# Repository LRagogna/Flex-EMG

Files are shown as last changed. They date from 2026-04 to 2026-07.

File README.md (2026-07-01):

# Flex-EMG

Notion Link: https://tabby-coat-711.notion.site/FlexEMG-110f756f6bd680bfb4d2c9bf16184d59

A wearable surface-electromyography (sEMG) platform that reads muscle activity
from the forearm, cleans it with a real-time digital filter chain, and
classifies hand gestures using a lightweight machine-learning model.

The project spans the full stack: a custom analog front-end (AFE) PCB, ESP32
firmware that streams ADC samples over WiFi, and a Python backend that filters
the signal, recognizes gestures, and broadcasts results to any client over
WebSocket.

> Built by the **Neurotech at Berkeley** Flex-EMG team, Spring 2026.

---

## How it works

```
 Forearm muscles
       │  surface electrodes
       ▼
 Analog Front-End PCB ── instrumentation amp → filtering → 24-bit ADC
       │  digital samples
       ▼
 ESP32-C3 firmware ─────── streams {"v": <adc>} over WiFi / serial
       │
       ▼
 Python backend ────────── bandpass 20–500 Hz + 60 Hz notch
       │                   Hudgins features → LDA gesture classifier
       ▼
 WebSocket broadcast ───── live frames to dashboards / notebooks / viewers
```

Each processed frame is streamed as JSON:

```json
{ "ts": 1713456789.12, "raw": 1.65, "filtered": 0.042, "gesture": "Fist Squeeze", "confidence": 0.97 }
```

---

## Hardware

The custom AFE board conditions a microvolt-level EMG signal into a clean
digital stream:

- **ADS1220** — 24-bit delta-sigma ADC with integrated PGA
- **OPA4322** — quad precision op-amps for the analog filter / gain stages
- **MCP4141** — digital potentiometer for programmable gain
- **ESP32-C3** — onboard wireless MCU for sampling and streaming

KiCad source (schematic, layout, footprints, and BOM) lives in
[`finalKiCad/`](finalKiCad/).

### Gallery

| | |
|:---:|:---:|
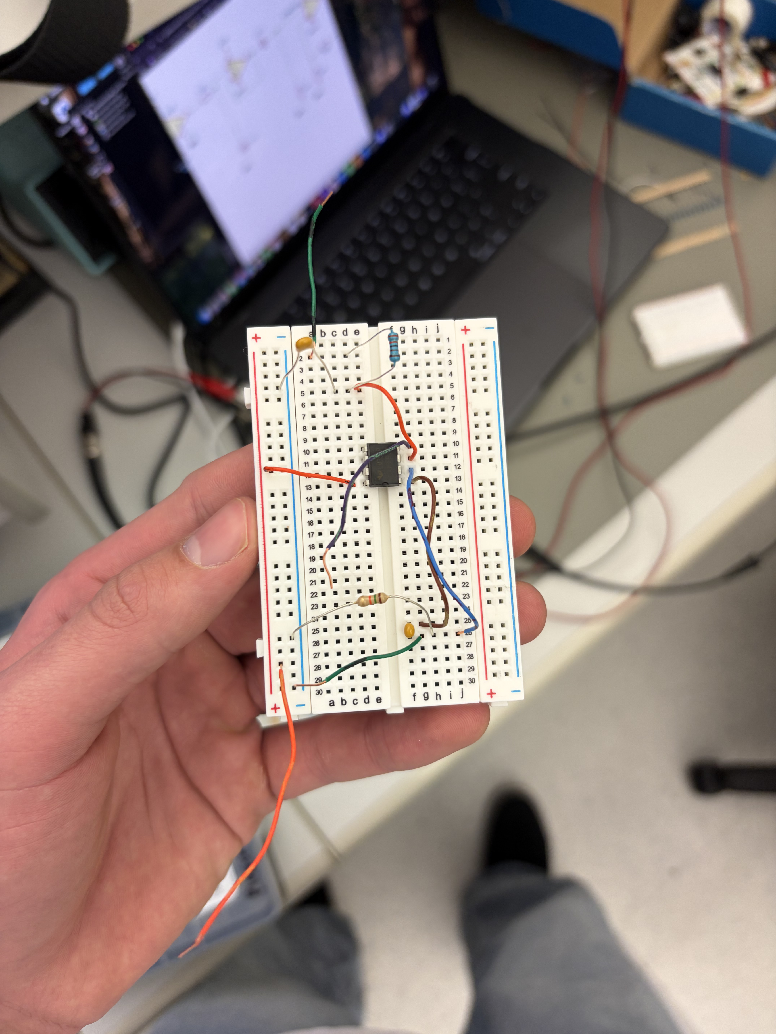
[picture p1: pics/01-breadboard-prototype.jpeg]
Breadboard prototype
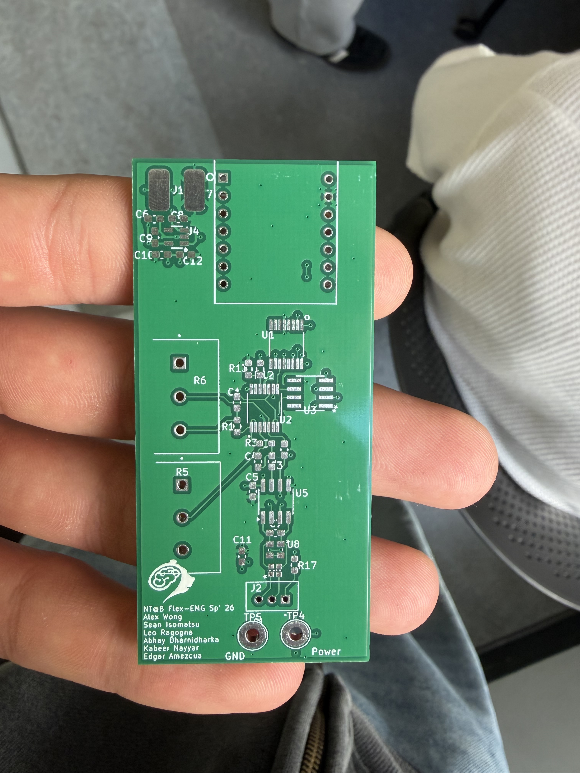
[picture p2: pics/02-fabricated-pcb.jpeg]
Fabricated PCB
| <br>**Breadboard prototype** of the front-end | <br>**Fabricated AFE board** fresh from the fab |
| Reflow station<br>**Reflow + rework bench** used for assembly | Assembly inspection<br>**Applying solder paste to board** |
| Microscope layout<br>**Layout under the scope** during placement | Soldered components<br>**Soldered ICs** — ADC and op-amp stages |

---

## Software

The backend lives in [`backend/`](backend/) and is fully documented in
[`backend/DOCS.md`](backend/DOCS.md). Key modules:

| Module | Role |
|---|---|
| `config.py` | Single source of truth for sample rate, filter, and connection settings |
| `signal_processor.py` | Real-time bandpass + 60 Hz notch filter chain (SciPy SOS) |
| `esp32_client.py` | WiFi/serial reader with auto-reconnect |
| `classifier.py` | Hudgins time-domain features → StandardScaler + LDA pipeline |
| `server.py` | WebSocket server that fans frames out to all clients |
| `main.py` | Production entry point (`--train`, `--classify`) |
| `test.py` | Hardware-free simulator with a live viewer and training UI |

---

## Getting started

### 1. Simulation (no hardware required)

```bash
cd backend
pip install -r requirements.txt
python test.py          # live matplotlib viewer
python test.py --text   # terminal table mode
```

Hold `1` / `2` to record the two gesture classes, press `T` to train, then `P`
to toggle live prediction. See [`backend/DOCS.md`](backend/DOCS.md) for the full
key map.

### 2. Real hardware

1. Flash `backend/esp32_firmware/emg_sender.ino` to the ESP32 (edit the WiFi and
   backend host lines first).
2. Point `config.py` at your board:
   ```python
   ESP32_MODE   = "websocket"
   ESP32_WS_URI = "ws://<your-esp32-ip>:81"
   ```
3. Collect data and run live classification:
   ```bash
   python main.py --train      # guided data collection
   python main.py --classify   # stream gestures over ws://0.0.0.0:8765
   ```

---

## Repository layout

```
backend/        Python signal-processing + ML pipeline (see DOCS.md)
finalKiCad/     KiCad project: schematic, PCB layout, footprints, BOM
pics/           Project photos
```

---

## Team

Neurotech at Berkeley — Flex-EMG, Spring 2026:
Alex Wong · Sean Isomatsu · Leo Ragogna · Abhay Bharnidharka · Kabeer Nayyar · Edgar Amazcua

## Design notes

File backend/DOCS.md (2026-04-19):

# FlexEMG Backend – Technical Reference

This document covers every module, class, and function in the backend.
It is written so that someone unfamiliar with the code can understand what
each piece does, how to configure it, and how the parts fit together.

---

## Table of Contents

1. [Project overview](#1-project-overview)
2. [Data flow](#2-data-flow)
3. [config.py – Global settings](#3-configpy--global-settings)
4. [signal_processor.py – EMG filter chain](#4-signal_processorpy--emg-filter-chain)
5. [esp32_client.py – ESP32 connection](#5-esp32_clientpy--esp32-connection)
6. [server.py – WebSocket broadcast server](#6-serverpy--websocket-broadcast-server)
7. [classifier.py – Gesture recognition](#7-classifierpy--gesture-recognition)
8. [main.py – Production entry point](#8-mainpy--production-entry-point)
9. [test.py – Simulation and training UI](#9-testpy--simulation-and-training-ui)
10. [esp32_firmware/emg_sender.ino – Arduino reference](#10-esp32_firmwareemg_senderino--arduino-reference)
11. [Workflow: simulation → real PCB](#11-workflow-simulation--real-pcb)

---

## 1. Project Overview

The backend receives raw 12-bit ADC samples from an ESP32 that is connected
to a forearm EMG circuit (0–3.3 V output). It applies a two-stage digital
filter to clean the signal, classifies the result into one of two gestures
using a trained machine-learning model, and streams everything in real time
over a WebSocket server to any connected client.

```
ESP32 (ADC)
    │  raw ADC counts  {"v": 2048}
    ▼
esp32_client.py   ← connects to ESP32 (WiFi WebSocket or USB serial)
    │  {adc: int, ts: float}
    ▼
signal_processor.py  ← bandpass 20–500 Hz  +  60 Hz notch
    │  {raw_voltage: float, filtered: float}
    ▼
classifier.py  (optional)  ← Hudgins features → LDA
    │  gesture: str, confidence: float
    ▼
server.py  ← WebSocket broadcast
    │  JSON frame to every connected client
    ▼
Dashboard / test.py viewer / any WebSocket client
```

---

## 2. Data Flow

### Sample journey, step by step

| Step | Where | What happens |
|---|---|---|
| 1 | ESP32 firmware | ADC samples the forearm signal at 2000 Hz and sends `{"v": 2048}` over WebSocket or serial |
| 2 | `esp32_client.py` | Receives the message, parses it, timestamps it, and puts `{adc: 2048, ts: 1713456789.1}` on an asyncio queue |
| 3 | `signal_processor.py` | Converts the ADC count to volts, runs it through the bandpass filter (20–500 Hz), then the 60 Hz notch filter |
| 4 | `classifier.py` (optional) | Every 200 ms a new analysis window is ready; six Hudgins features are extracted and passed to the LDA model, which returns a gesture label and confidence |
| 5 | `server.py` | Broadcasts a JSON frame to all connected clients: `{"ts": …, "raw": …, "filtered": …, "gesture": …, "confidence": …}` |

### Broadcast frame format

```json
{
  "ts":         1713456789.123,
  "raw":        1.6504,
  "filtered":   0.0421,
  "gesture":    "Fist Squeeze",
  "confidence": 0.9712
}
```

`gesture` and `confidence` are `null` when the classifier is not running.

---

## 3. `config.py` – Global Settings

Single source of truth for every tunable parameter. Edit this file to
match your hardware before running the backend.

### Signal parameters

| Variable | Default | Description |
|---|---|---|
| `SAMPLE_RATE` | `2000` Hz | Must match the ESP32 firmware's ADC rate. 2000 Hz gives a Nyquist frequency of 1000 Hz, safely above the 500 Hz EMG upper limit. |
| `ADC_RESOLUTION` | `12` bits | ESP32 ADC is 12-bit, so values range 0–4095. |
| `ADC_VREF` | `3.3` V | Reference voltage of the ADC. All raw counts are scaled against this. |

### Filter parameters

| Variable | Default | Description |
|---|---|---|
| `BANDPASS_LOW_HZ` | `20.0` | Lower cutoff of the EMG bandpass filter. Removes slow drift and DC. |
| `BANDPASS_HIGH_HZ` | `500.0` | Upper cutoff. Attenuates high-frequency noise above the EMG band. |
| `BANDPASS_ORDER` | `4` | Butterworth filter order. Higher = steeper roll-off but more group delay. |
| `NOTCH_FREQ_HZ` | `60.0` | Frequency to notch out (power-line interference). Change to 50.0 in Europe. |
| `NOTCH_Q` | `30.0` | Quality factor of the notch. Higher Q = narrower notch. The current value achieves −254 dB at exactly 60 Hz. |

### ESP32 connection

| Variable | Default | Description |
|---|---|---|
| `ESP32_MODE` | `"websocket"` | Transport: `"websocket"` (WiFi) or `"serial"` (USB/UART). |
| `ESP32_WS_URI` | `"ws://192.168.1.100:81"` | IP and port of the ESP32 WebSocket server. Change this to match your ESP32's IP address on your network. |
| `ESP32_WS_RECONNECT_DELAY` | `3.0` s | How long to wait before attempting to reconnect after a dropped connection. |
| `ESP32_SERIAL_PORT` | `"/dev/tty.usbserial-0001"` | Serial port path (macOS). Windows uses `"COM3"`, Linux uses `"/dev/ttyUSB0"`. |
| `ESP32_BAUD_RATE` | `115200` | Must match `Serial.begin(115200)` in the Arduino sketch. |

### Backend server

| Variable | Default | Description |
|---|---|---|
| `SERVER_HOST` | `"0.0.0.0"` | Listen on all network interfaces. Change to `"127.0.0.1"` to restrict to localhost. |
| `SERVER_PORT` | `8765` | Port that downstream clients (dashboards, notebooks) connect to. |

---

## 4. `signal_processor.py` – EMG Filter Chain

### What it does

Converts raw 12-bit ADC values to volts and applies a two-stage causal
digital filter in real time:

1. **Bandpass filter** (4th-order Butterworth, 20–500 Hz) – keeps only the
   physiological EMG frequency range and removes DC offset.
2. **Notch filter** (IIR, 60 Hz, Q = 30) – eliminates power-line interference.

Both filters are implemented as **second-order sections (SOS)** which are
numerically stable even at high orders. Running filter state (`zi`) is kept
between calls so each sample is processed causally with no look-ahead.

### Class: `SignalProcessor`

#### `__init__(...)`

Designs both filters using `scipy.signal` and initialises their state
vectors to mid-scale (1.65 V) so transients settle within a few milliseconds
rather than tens of milliseconds.

Parameters (all optional; defaults come from `config.py`):

| Parameter | Description |
|---|---|
| `sample_rate` | ADC sample rate in Hz |
| `bandpass_low` | Lower bandpass cutoff in Hz |
| `bandpass_high` | Upper bandpass cutoff in Hz |
| `bandpass_order` | Butterworth filter order |
| `notch_freq` | Notch center frequency in Hz |
| `notch_q` | Notch quality factor |
| `adc_resolution` | ADC bit depth (12 for ESP32) |
| `adc_vref` | ADC reference voltage in volts |

#### `adc_to_voltage(raw_adc: int) → float`

Converts a raw 12-bit ADC count (0–4095) to volts (0.0–3.3 V).

```python
voltage = raw_adc / 4095.0 * 3.3
```

#### `process_sample(raw_adc: int) → dict`

Processes **one sample** through the full filter chain. This is the
primary method used by the real-time pipeline.

Returns:
```python
{
    "raw_voltage": 1.6504,   # ADC count → volts, no filtering
    "filtered":    0.0421    # after bandpass + notch
}
```

Calling this in a tight loop is safe and efficient because `sosfilt` with
stored state (`zi`) is O(1) per sample.

#### `process_batch(raw_adc_array: list[int]) → dict`

Processes a list of samples in one vectorised NumPy call. More efficient
than calling `process_sample` in a Python loop when you have a large batch.

Returns:
```python
{
    "raw_voltage": np.ndarray,   # shape (N,)
    "filtered":    np.ndarray    # shape (N,)
}
```

#### `reset()`

Resets both filter state vectors to mid-scale. Call this whenever the
data stream restarts (e.g. after the ESP32 reconnects) to avoid a
transient spike from stale state.

---

## 5. `esp32_client.py` – ESP32 Connection

### What it does

Establishes and maintains the connection to the ESP32. It runs as an
asyncio coroutine so it never blocks the rest of the pipeline. If the
connection drops it waits `ESP32_WS_RECONNECT_DELAY` seconds and
automatically reconnects.

Each received message is parsed and placed on an asyncio queue as:
```python
{"adc": 2048, "ts": 1713456789.123}
```

### Supported message formats from the ESP32

```
2048          ← plain integer (simplest)
{"v": 2048}   ← JSON with key "v" (used by the reference Arduino sketch)
```

Anything else is silently ignored and logged at DEBUG level.

### `create_esp32_reader(queue, on_connect, on_disconnect) → coroutine`

The only public function. Returns the correct coroutine based on
`config.ESP32_MODE`:

- `"websocket"` → `_ws_reader` (connects to the ESP32's WebSocket server)
- `"serial"` → `_serial_reader` (reads from USB/UART)

**Parameters:**

| Parameter | Description |
|---|---|
| `queue` | `asyncio.Queue` where parsed samples are deposited |
| `on_connect` | Optional callback called each time a connection is established. The pipeline uses this to call `processor.reset()`. |
| `on_disconnect` | Optional callback called when the connection is lost |

**Usage in the pipeline:**
```python
task = asyncio.create_task(
    create_esp32_reader(raw_queue, on_connect=cb)
)
```

---

## 6. `server.py` – WebSocket Broadcast Server

### What it does

Maintains a set of connected WebSocket clients and fans out every processed
sample to all of them simultaneously. Clients connect and just listen;
the server never reads from them.

### Class: `BroadcastServer`

#### `broadcast(ts, raw_voltage, filtered, gesture=None, confidence=None)`

Serialises one sample frame to JSON and sends it to every connected client.
Stale connections that have already closed are silently removed from the
client set.

Parameters:

| Parameter | Type | Description |
|---|---|---|
| `ts` | `float` | Unix timestamp of the sample |
| `raw_voltage` | `float` | Raw ADC reading in volts |
| `filtered` | `float` | Filtered EMG voltage in volts |
| `gesture` | `str \| None` | Predicted gesture name (only when classifier is running) |
| `confidence` | `float \| None` | Prediction confidence 0–1 |

#### `serve()`

Starts the WebSocket server on `SERVER_HOST:SERVER_PORT` and runs
indefinitely. Called as an asyncio task.

### Connecting a client

Any WebSocket client can subscribe by connecting to
`ws://<host>:8765` (or whatever `SERVER_PORT` is set to).

Example with the Python `websockets` library:
```python
import asyncio, json, websockets

async def main():
    async with websockets.connect("ws://localhost:8765") as ws:
        async for message in ws:
            frame = json.loads(message)
            print(frame["filtered"], frame.get("gesture"))

asyncio.run(main())
```

---

## 7. `classifier.py` – Gesture Recognition

### What it does

Trains and runs a two-class EMG gesture recogniser. The two classes are:

| Label | Gesture |
|---|---|
| `0` | **Fist Squeeze** — strong, broad-spectrum forearm activation |
| `1` | **Wrist Flexion Up** — lighter, moderate-frequency dorsal activation |

The pipeline is:
1. Collect 200 ms windows of filtered EMG (400 samples at 2000 Hz).
2. Extract 6 Hudgins time-domain features from each window.
3. Feed features into a `StandardScaler → LinearDiscriminantAnalysis` sklearn pipeline.

### Key constants

| Constant | Value | Description |
|---|---|---|
| `CLASSES` | `{0: "Fist Squeeze", 1: "Wrist Flexion Up"}` | Label-to-name mapping |
| `WINDOW_SAMPLES` | 400 | Samples per analysis window (200 ms at 2 kHz) |
| `STEP_SAMPLES` | 200 | Samples between consecutive windows (100 ms, 50% overlap) |
| `MIN_SAMPLES_PER_CLASS` | 15 | Minimum windows required per class before training is allowed |
| `DEFAULT_MODEL_PATH` | `model.pkl` | Default save/load location |

### Hudgins feature set (6 features)

These are the standard time-domain features for real-time EMG pattern
recognition, proven in prosthetics research since 1993.

| Feature | Formula | What it captures |
|---|---|---|
| **MAV** | `mean(|x|)` | Overall signal amplitude / muscle effort |
| **RMS** | `sqrt(mean(x²))` | Signal power |
| **WL** | `sum(|x[i] - x[i-1]|)` | Waveform complexity / firing rate |
| **VAR** | `var(x)` | Signal variability |
| **ZC** | count of zero crossings | Frequency content estimate |
| **SSC** | count of slope sign changes | Frequency content, noise-robust |

### Class: `EMGClassifier`

#### `extract_features(window: np.ndarray) → np.ndarray`

Static method. Takes a 1-D array of `WINDOW_SAMPLES` filtered voltage
values and returns a feature vector of shape `(6,)`.

This is the same method used internally during both training and inference,
so it is the exact thing to call if you want to inspect what the model sees.

#### `add_training_sample(window, class_label)`

Adds one labelled window to the internal training buffer.
- `window` — 1-D array of `WINDOW_SAMPLES` filtered voltage samples
- `class_label` — `0` (Fist Squeeze) or `1` (Wrist Flexion Up)

Nothing is computed here; features are extracted immediately but the model
is not updated until `train()` is called.

#### `train() → dict`

Fits the StandardScaler + LDA pipeline on all collected windows.

Raises `ValueError` if any class has fewer than `MIN_SAMPLES_PER_CLASS` windows.

Returns a dict:
```python
{
    "accuracy":  0.975,    # training-set accuracy (0–1)
    "n_samples": 40,       # total windows used
    "counts":    {0: 20, 1: 20}
}
```

**Note:** Training accuracy is measured on the same data used to fit the
model (in-sample). It will be high by design. When the PCB is ready, collect
data across multiple sessions to get a better estimate of true generalisation.

#### `predict(window: np.ndarray) → tuple[int, float]`

Classifies one 200 ms window. Returns `(class_label, confidence)` where
`confidence` is the probability assigned to the predicted class by the LDA
model.

Raises `RuntimeError` if `train()` has not been called yet.

#### `save(path="model.pkl")`

Serialises the trained pipeline to disk using pickle.
Raises `RuntimeError` if the model has not been trained.

#### `load(path="model.pkl") → EMGClassifier` (class method)

Loads a previously saved model. Raises `FileNotFoundError` if the file
does not exist.

#### `clear_training_data()`

Discards all collected windows and resets the model to untrained state.
Use this to start a fresh training session without restarting the process.

#### Properties

| Property | Type | Description |
|---|---|---|
| `is_trained` | `bool` | Whether the model has been fitted |
| `train_accuracy` | `float \| None` | In-sample accuracy from the last `train()` call |
| `training_counts` | `dict[int, int]` | Windows collected per class so far |

---

## 8. `main.py` – Production Entry Point

### Normal operation

```bash
python main.py
```

Connects to the real ESP32, filters the signal, and streams processed data
to `ws://0.0.0.0:8765`. No classification is performed unless `--classify`
is passed.

### `--train` flag — interactive training session

```bash
python main.py --train
```

Runs a guided data collection session on the **real ESP32**. The terminal
prompts you to perform each gesture and records labelled windows from the
live filtered signal. When both classes have enough data, the model is
trained and saved to `model.pkl`.

**Step-by-step session:**

```
>> Ready to record 'Fist Squeeze'. Perform the movement and press Enter …
   [hold fist squeeze for 10 seconds]
>> Rest. Press Enter when ready for the next movement …
   [relax, then press Enter]
>> Ready to record 'Wrist Flexion Up'. Perform the movement and press Enter …
   [hold wrist flexion up for 10 seconds]
>> Rest. Press Enter when ready for the next movement …
   Training classifier …
   Training complete | accuracy=97.5% | samples=160 | counts={Fist Squeeze: 80, Wrist Flexion Up: 80}
   Model saved to model.pkl
```

The ESP32 must already be connected and streaming before this command is run.

### `--classify` flag — live gesture prediction

```bash
python main.py --classify
```

Loads `model.pkl` and attaches the classifier to the pipeline. Every
`STEP_SAMPLES` (100 ms) a prediction is made and included in the broadcast
frame:

```json
{"ts": 1.0, "raw": 1.65, "filtered": 0.042, "gesture": "Fist Squeeze", "confidence": 0.97}
```

Exits with an error if `model.pkl` does not exist. Run `--train` first.

### `--train` and `--classify` are mutually exclusive

You cannot pass both flags at once. Train first, then run with `--classify`.

### `pipeline(queue, processor, server, classifier=None)` — async function

The core data-processing coroutine. Continuously drains samples from the
queue, calls `processor.process_sample()`, optionally runs the classifier,
and broadcasts the result.

When `classifier` is not `None`, a rolling deque of `WINDOW_SAMPLES` filtered
values is maintained. Every `STEP_SAMPLES`-th call triggers a prediction,
and the result is attached to the next broadcast frame.

This function is also **imported by `test.py`** so both the simulation and
production paths use the same filtering code.

---

## 9. `test.py` – Simulation and Training UI

### Purpose

Runs the entire system — mock ESP32, backend pipeline, and live viewer — in
a single terminal with no hardware required. This is the primary tool for:

- Verifying the filter chain works before the PCB arrives
- Training the gesture classifier on simulated signals
- Testing prediction logic

### Running

```bash
python test.py           # live matplotlib plot (default)
python test.py --text    # scrolling table output (no display needed)
```

---

### Keyboard controls

The same keys work in both plot and text mode.

#### Movement simulation (no training effect)

| Key | Movement | Signal character |
|-----|---|---|
| `W` | Fingers Up | Medium amplitude, 30–160 Hz |
| `S` | Squeeze | High amplitude, 20–350 Hz |
| `A` | Wrist Left | Medium-low amplitude, 25–140 Hz |
| `D` | Wrist Right | Medium amplitude, 25–180 Hz |
| Space / any other | Release → Rest | Near-zero amplitude |

**Plot mode:** hold the key to keep the muscle active; release to relax.
The filtered signal amplitude rises with a ~30 ms attack and falls with
a ~500 ms decay, matching real muscle activation timing.

**Text mode:** each press triggers a 1.5-second burst and then
automatically returns to Rest (terminal input cannot detect key releases).

#### Training keys

| Key | Class recorded | Mock signal activated |
|-----|---|---|
| Hold `1` | **Fist Squeeze** (class 0) | High-amplitude broadband signal (same as `S`) |
| Hold `2` | **Wrist Flexion Up** (class 1) | Medium-amplitude mid-frequency signal (same as `W`) |

While a training key is held, every completed 200 ms window of filtered
EMG is automatically labelled and added to the classifier's training
buffer. The progress bars in the classifier panel (or the Train column in
text mode) update in real time.

#### Classifier actions

| Key | Action |
|-----|---|
| `T` | Train the classifier on all collected windows. If training succeeds, the model is automatically saved to `model.pkl`. |
| `P` | Toggle live prediction on/off. Predictions appear in the classifier panel or the Prediction column. |
| `C` | Clear all training data and reset the model to untrained state. |

---

### Plot mode — three panels

#### Top panel: Raw signal
Shows the ADC reading converted to volts with DC removed for display.
The regular 60 Hz oscillation from power-line interference is visible at rest.

#### Middle panel: Filtered signal
Shows the same signal after the bandpass and notch filters. The 60 Hz wave
is absent. When a movement key is held, the signal amplitude increases in
proportion to the movement's configured amplitude.

#### Bottom panel: Classifier status

Left column — training progress:
```
Fist Squeeze          [████████░░░░░░░░] 8/15
Wrist Flexion Up      [░░░░░░░░░░░░░░░░] 0/15

Model: not trained  (press T)
```

The bar for the class currently being recorded turns yellow. Once 15 windows
are collected for both classes and `T` is pressed, the bar changes to green
and accuracy is shown.

Right column — live prediction:
```
PREDICTION
Fist Squeeze
97% confidence
```

The gesture name is coloured red for Fist Squeeze and green for Wrist
Flexion Up.

---

### Text mode — live table

One summary row is printed per second:

```
  Time  Movement            Train     Raw RMS   Filt RMS   Reduction  Prediction
─────────────────────────────────────────────────────────────────────────────────
    1.2  Rest                 --       0.42368    0.01110       31.7 dB  --
    2.5  Squeeze           FistSq     0.53177    0.33322        4.1 dB  --
    4.9  Rest                 --       0.42315    0.01047       32.1 dB  Fist Squeeze (97%)
```

Columns:

| Column | Description |
|---|---|
| Time | Elapsed seconds since first sample |
| Movement | Currently active mock movement |
| Train | Class being recorded (`FistSq` / `WristF` / `--`) |
| Raw RMS | RMS of the last 2000 raw samples (DC-removed). High value = 60 Hz interference present. |
| Filt RMS | RMS of the filtered signal. Tracks the actual muscle amplitude. |
| Reduction | `20 × log10(Raw RMS / Filt RMS)` in dB. ~32 dB at rest confirms the notch is working. |
| Prediction | Gesture name and confidence when prediction mode is on. |

---

### Internal components

#### `MOVEMENTS` dict

Defines how the mock ESP32 generator shapes its output for each key.
Each entry specifies:
- `amplitude` — target peak voltage of the muscle noise component (V)
- `freq_lo / freq_hi` — bandpass range that shapes the noise for this muscle group (Hz)

To add a new simulated movement, add an entry here and assign it a key.

#### `EMGGenerator` class

Produces one integer ADC sample per call for the mock ESP32.

The signal is composed of:
1. **1.65 V DC bias** — matches the mid-rail of the real 0–3.3 V circuit
2. **Gaussian noise** shaped through the movement's bandpass filter, scaled
   by a smoothed amplitude envelope
3. **0.6 V 60 Hz sine wave** — constant power-line interference

The amplitude envelope uses a first-order IIR smoother so activations
rise quickly (~30 ms) and relax slowly (~500 ms), matching real muscle timing.

#### `ClassificationState` class

Coordinates the sliding window buffer, training, and inference. This is the
glue between the incoming sample stream and the classifier.

Key methods:

| Method | Description |
|---|---|
| `push_sample(filtered)` | Feed one filtered voltage sample. When the window is full and enough samples have stepped by, either records a training window or makes a prediction depending on current state. |
| `set_train_class(label, burst_secs)` | Called by keyboard handler when a training key is pressed. Sets the label that will be applied to the next windows. `burst_secs` makes it auto-expire (text mode). |
| `release_train_class()` | Called on key release (plot mode). Stops recording. |
| `train()` | Calls `clf.train()` and saves the result to `model.pkl` on success. Updates `status_msg` with the outcome. |
| `clear()` | Resets everything: clears training buffer, last prediction, status message. |
| `predict_on` | Boolean flag toggled by the `P` key. When `True` and the model is trained, predictions are generated every `STEP_SAMPLES`. |
| `last_pred` | `(label, confidence)` tuple of the most recent prediction, or `None`. |
| `counts` | Dict of `{class_label: n_windows}` collected so far. |

#### Thread safety

The mock signal generator runs in a background asyncio thread and reads
`_movement_key` via `get_movement()`. The keyboard handler (main thread or
keyboard daemon thread) writes it via `set_movement()`. Both are protected
by `_mv_lock`.

`ClassificationState._train_class` is similarly protected by an internal
lock because the keyboard daemon thread writes it while the viewer loop
(main thread) reads it in `push_sample()`. Everything else in
`ClassificationState` is only touched by the main thread.

---

## 10. `esp32_firmware/emg_sender.ino` – Arduino Reference

A reference Arduino sketch for the ESP32 that:
- Reads GPIO 34 (ADC1, input-only pin, no pull-up) at 2000 Hz
- Configures 12-bit resolution with 11 dB attenuation (full 0–3.3 V range)
- Sends each sample as `{"v": <adc_count>}` over WiFi WebSocket

Libraries required (Arduino Library Manager):
- **ArduinoWebsockets** by Gil Maimon
- **ArduinoJson** by Benoit Blanchon

Before flashing, edit these lines to match your network and backend:
```cpp
const char* WIFI_SSID     = "YOUR_SSID";
const char* WIFI_PASSWORD = "YOUR_PASSWORD";
const char* BACKEND_HOST  = "192.168.1.50";   // IP of the machine running main.py
const uint16_t BACKEND_PORT = 8765;
```

---

## 11. Workflow: Simulation → Real PCB

### Phase 1 — Simulation (no hardware)

```bash
cd backend
pip install -r requirements.txt
python test.py
```

1. Hold `1` for several seconds to collect Fist Squeeze training data.
2. Hold `2` for several seconds to collect Wrist Flexion Up training data.
3. Watch the progress bars reach 15/15 for each class.
4. Press `T` to train. The model is saved to `model.pkl`.
5. Press `P` to enable prediction. Hold `1` or `2` and verify the label
   shown in the classifier panel matches the movement.

### Phase 2 — Real PCB arrives

1. Flash `esp32_firmware/emg_sender.ino` to your ESP32.
2. Update `config.py`:
   ```python
   ESP32_MODE    = "websocket"
   ESP32_WS_URI  = "ws://<your-esp32-ip>:8765"
   ```
3. Collect real training data:
   ```bash
   python main.py --train
   ```
   Follow the prompts: hold each movement for 10 seconds when asked.
   The model is saved to `model.pkl` when done.

4. Run the backend with live classification:
   ```bash
   python main.py --classify
   ```
   Every WebSocket frame now includes `"gesture"` and `"confidence"` fields.

5. To retrain at any time (e.g. after placing electrodes differently),
   delete `model.pkl` and run `python main.py --train` again.

### Switching between simulation and real hardware

The `classifier.py` API is identical in both cases. The only thing that
changes is where the filtered samples come from:

| Source | How samples arrive at the classifier |
|---|---|
| Simulation (`test.py`) | `ClassificationState.push_sample()` is called in the viewer loop as frames arrive from the mock ESP32 |
| Real hardware (`main.py`) | The `pipeline()` coroutine maintains a sliding deque and calls `classifier.predict()` every `STEP_SAMPLES` |

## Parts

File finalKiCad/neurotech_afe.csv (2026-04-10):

Reference | Qty | Value | DNP | Exclude from BOM | Exclude from Board | Footprint | Datasheet
10k1 | 1 | R_Small |  |  |  | Resistor_SMD:R_0201_0603Metric_Pad0.64x0.40mm_HandSolder | ~
20k1,50k1 | 2 | R_Potentiometer |  |  |  | Potentiometer_THT:Potentiometer_Bourns_3362P_Vertical | ~
C1 | 1 | 10nF |  |  |  | Capacitor_SMD:C_0201_0603Metric_Pad0.64x0.40mm_HandSolder | ~
C2 | 1 | 22nF |  |  |  | Capacitor_SMD:C_0201_0603Metric_Pad0.64x0.40mm_HandSolder | ~
C3 | 1 | 1uF |  |  |  | Capacitor_SMD:C_0201_0603Metric_Pad0.64x0.40mm_HandSolder | ~
C4 | 1 | 2.2uF |  |  |  | Capacitor_SMD:C_0201_0603Metric_Pad0.64x0.40mm_HandSolder | ~
C5 | 1 | 0.1u |  |  |  | Capacitor_SMD:C_0201_0603Metric_Pad0.64x0.40mm_HandSolder | ~
C6 | 1 | 10u |  |  |  | Capacitor_SMD:C_0201_0603Metric_Pad0.64x0.40mm_HandSolder | ~
C7 | 1 | C |  |  |  | Capacitor_SMD:C_0201_0603Metric_Pad0.64x0.40mm_HandSolder | ~
C8,C9 | 2 | 1 uF |  |  |  | Capacitor_SMD:C_0201_0603Metric_Pad0.64x0.40mm_HandSolder | ~
C10,C11 | 2 | 0.1 uF |  |  |  | Capacitor_SMD:C_0201_0603Metric_Pad0.64x0.40mm_HandSolder | ~
C12 | 1 | 100nF |  |  |  | Capacitor_SMD:C_0201_0603Metric_Pad0.64x0.40mm_HandSolder | ~
D1,D2 | 2 | BAT54S |  |  |  | Package_TO_SOT_SMD:SOT-23 | https://www.diodes.com/assets/Datasheets/ds11005.pdf
R1,R12,R13 | 3 | 10k |  |  |  | Resistor_SMD:R_0201_0603Metric_Pad0.64x0.40mm_HandSolder | ~
R2 | 1 | 510 |  |  |  | Resistor_SMD:R_0201_0603Metric_Pad0.64x0.40mm_HandSolder | ~
R17 | 1 | 100k |  |  |  | Resistor_SMD:R_0201_0603Metric_Pad0.64x0.40mm_HandSolder | ~
RN1 | 1 | 3.3k |  |  |  | ResistorArray_SMD:R_Array_Convex_4x0805 | ~
RN2 | 1 | 1M |  |  |  | ResistorArray_SMD:R_Array_Convex_4x0805 | ~
TP1,TP2,TP3 | 3 | TestPoint |  |  |  | TestPoint:TestPoint_THTPad_D2.0mm_Drill1.0mm | ~
U1 | 1 | ADS1220xPW |  |  |  | Package_SO:TSSOP-16_4.4x5mm_P0.65mm | http://www.ti.com/lit/ds/symlink/ads1220.pdf
U2 | 1 | Opamp_Quad |  |  |  | Package_SO:SOIC-14_3.9x8.7mm_P1.27mm | ~
U4 | 1 | TLV70033_SOT23-5 |  |  |  | Package_TO_SOT_SMD:SOT-23-5 | http://www.ti.com/lit/ds/symlink/tlv700.pdf
U5 | 1 | AD8226ARZ |  |  |  | Package_SO:SOIC-8_3.9x4.9mm_P1.27mm | https://www.analog.com/media/en/technical-documentation/data-sheets/AD8226.pdf
U7 | 1 | 113991054 |  |  |  | 113991054:MODULE_113991054

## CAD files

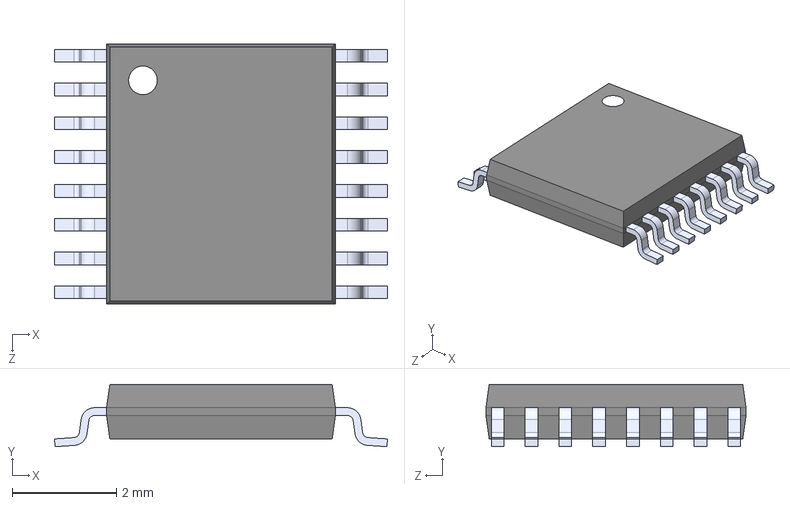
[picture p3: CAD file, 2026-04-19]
finalKiCad/ADS1220IPW/ADS1220IPW.step
6.40 x 1.20 x 5.00 mm

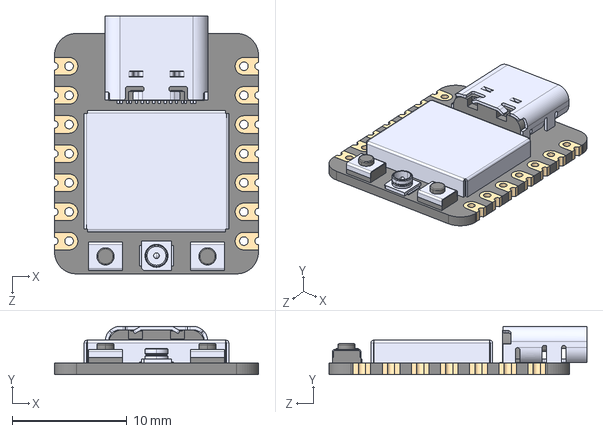
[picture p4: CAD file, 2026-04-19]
finalKiCad/ESP32C3/ESP32C3.step
17.8 x 4.21 x 22.5 mm

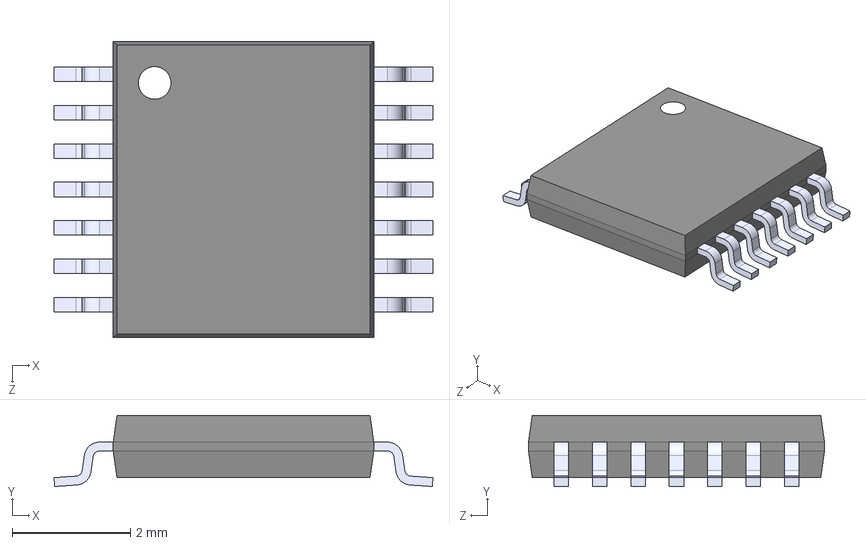
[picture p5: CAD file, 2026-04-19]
finalKiCad/OPA4322AIPWR/OPA4322AIPWR.step
6.40 x 1.20 x 5.00 mm

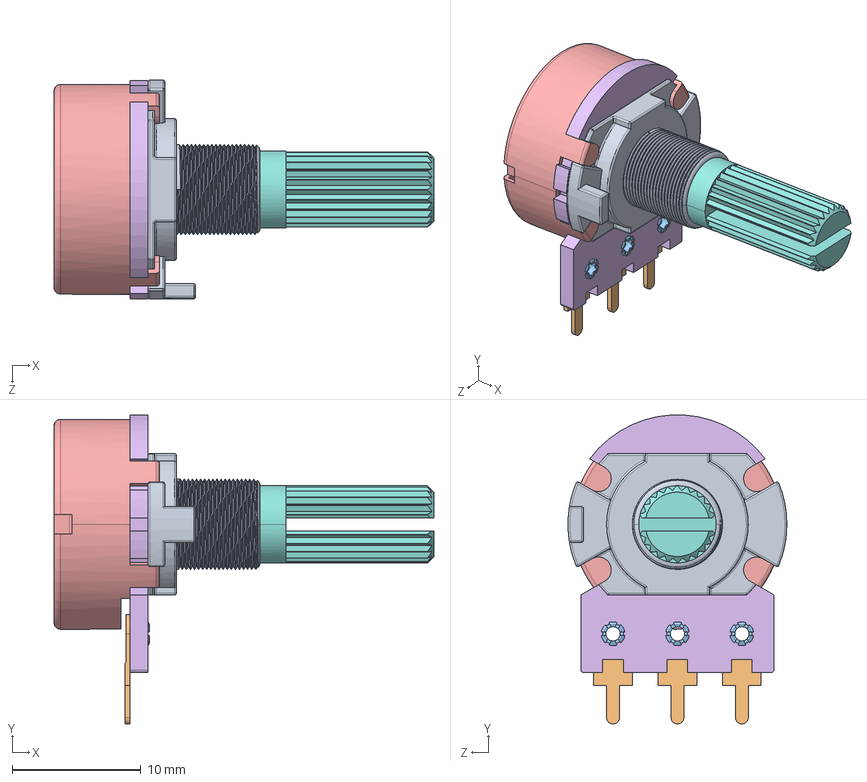
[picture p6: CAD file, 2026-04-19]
finalKiCad/PTN16_A20120K1B1/PTN16-A20120K1B1.step
29.5 x 24.0 x 17.0 mm
PTN16_1 BUSHING
PTN16-A_1 HOUSING
PTN16_20K1_SHAFT

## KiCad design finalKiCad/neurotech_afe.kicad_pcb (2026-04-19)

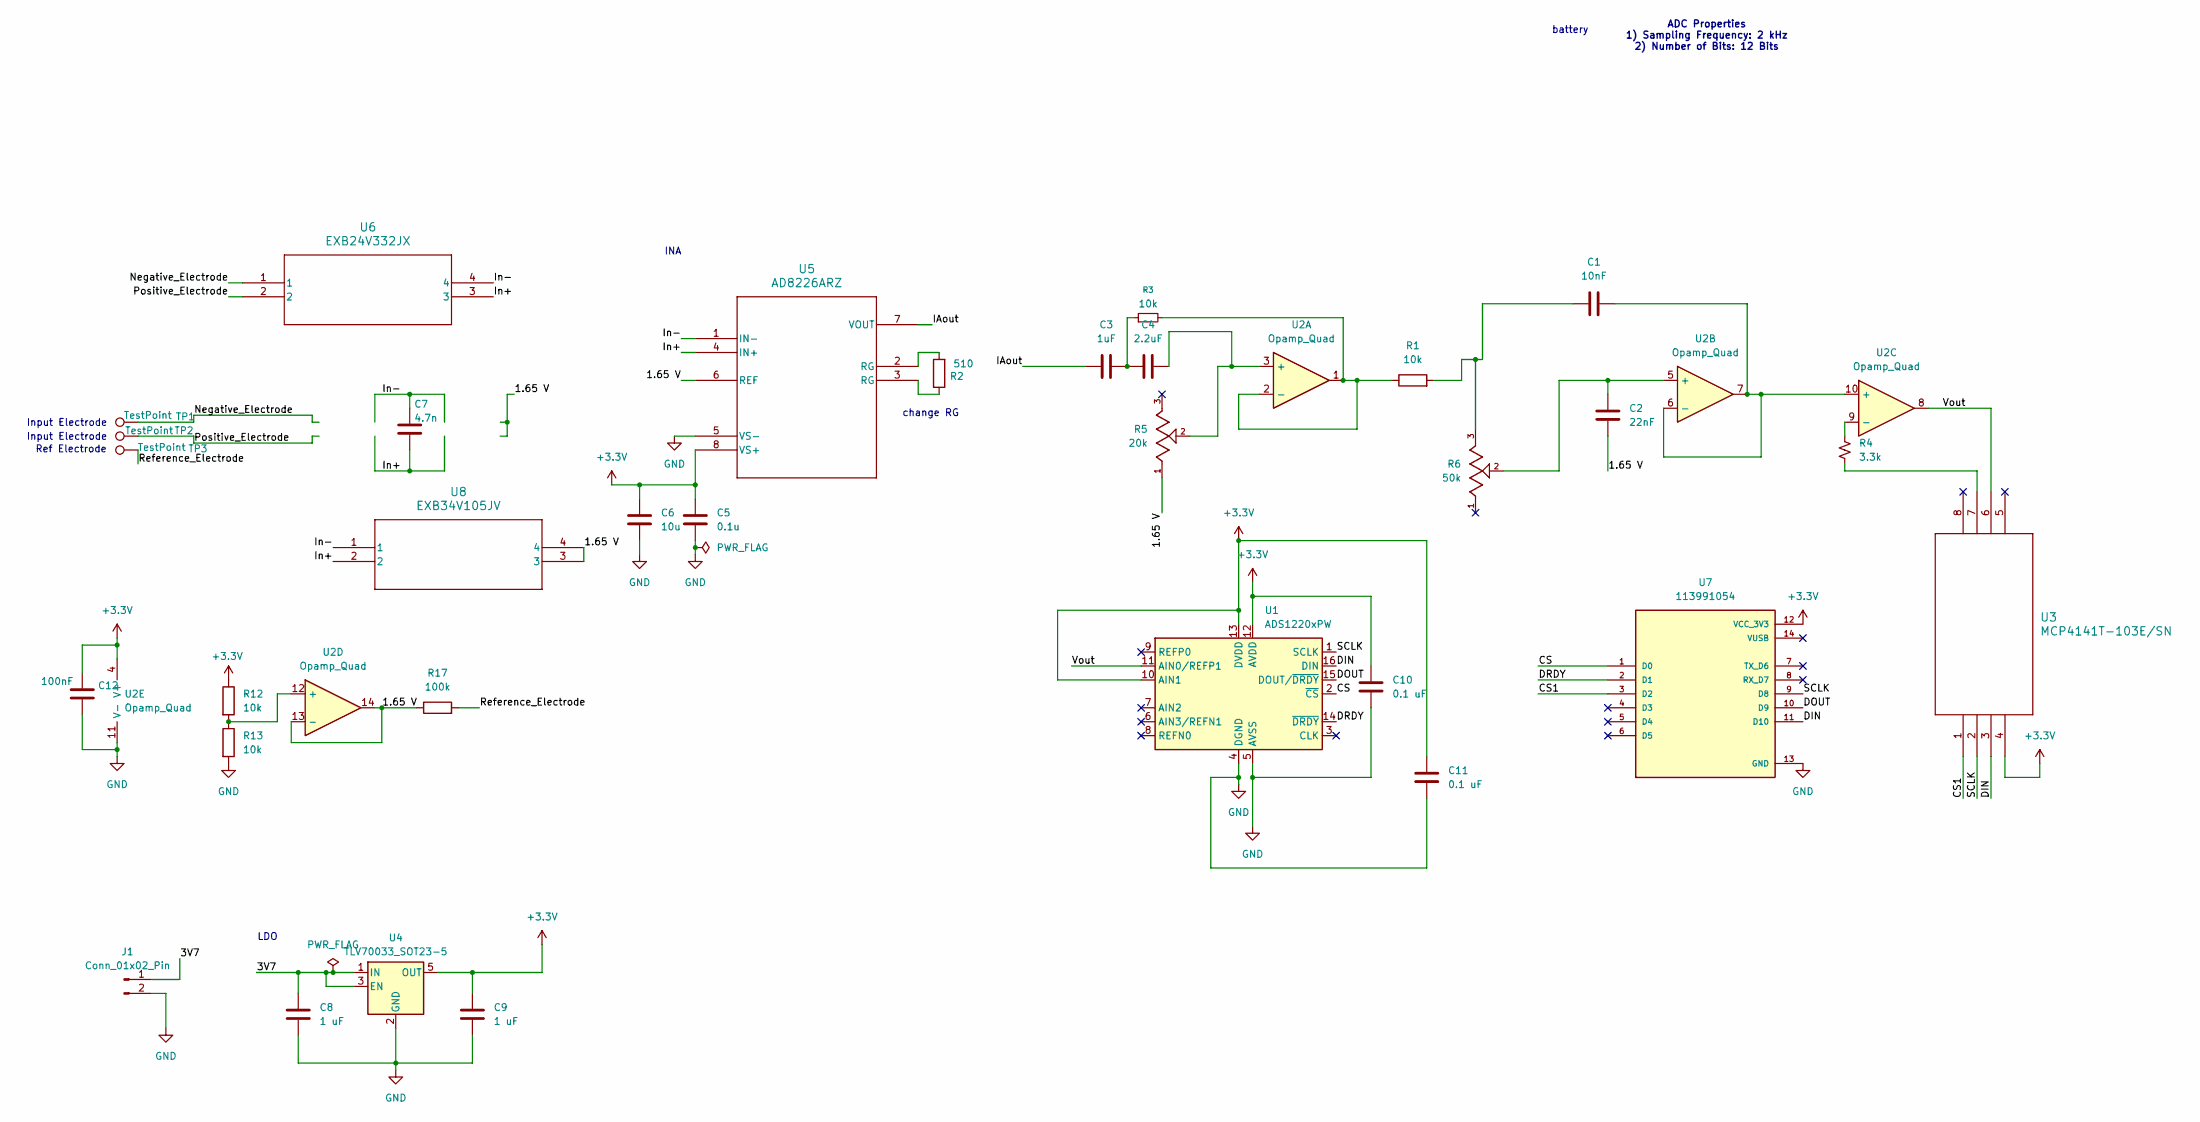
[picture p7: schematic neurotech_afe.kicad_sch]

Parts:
C1: 10nF; C_0603_1608Metric_Pad1.08x0.95mm_HandSolder
C2: 22nF; C_0603_1608Metric_Pad1.08x0.95mm_HandSolder
C3: 1uF; C_0603_1608Metric_Pad1.08x0.95mm_HandSolder
C4: 2.2uF; C_0603_1608Metric_Pad1.08x0.95mm_HandSolder
C5: 0.1u; C_0603_1608Metric_Pad1.08x0.95mm_HandSolder
C6: 10u; C_0603_1608Metric_Pad1.08x0.95mm_HandSolder
C7: 4.7n; C_0603_1608Metric_Pad1.08x0.95mm_HandSolder
C8, C9: 1 uF; C_0603_1608Metric_Pad1.08x0.95mm_HandSolder
C10, C11: 0.1 uF; C_0603_1608Metric_Pad1.08x0.95mm_HandSolder
C12: 100nF; C_0603_1608Metric_Pad1.08x0.95mm_HandSolder
J1: Conn_01x02_Pin; BATT_CONN
R1, R3, R12, R13: 10k; R_0603_1608Metric_Pad0.98x0.95mm_HandSolder
R2: 510; R_0603_1608Metric_Pad0.98x0.95mm_HandSolder
R4: 3.3k; R_0603_1608Metric_Pad0.98x0.95mm_HandSolder
R5: 20k; POT_PTN16-A20120K1B1; PARTREV 1.0
R6: 50k; POT_PTN16-A20120K1B1; PARTREV 1.0
R17: 100k; R_0603_1608Metric_Pad0.98x0.95mm_HandSolder
TP1, TP2, TP3: TestPoint; TestPoint_THTPad_D4.0mm_Drill2.0mm
U1: ADS1220xPW; SOP65P640X120-16N
U2: Opamp_Quad; SOP65P640X120-14N
U3: MCP4141T-103E/SN; SOIC8-N_MC_MCH
U4: TLV70033_SOT23-5; SOT-23-5
U5: AD8226ARZ; SOIC-8_3.9x4.9mm_P1.27mm
U6: EXB24V332JX; C_ARRAY_EXB24V_PAN
U7: 113991054; ESP32C3; PARTREV 23/05/2022
U8: EXB34V105JV; C_ARRAY_EXB34V_PAN

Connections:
+3.3V: C5.1, C6.1, C9.1, C10.1, C11.1, C12.1, R12.1, U1.10 (AIN1), U1.12 (AVDD), U1.13 (DVDD), U2.4 (V+), U3.4, U4.5 (OUT), U5.8 (VS+), U7.12 (VCC_3V3)
/1.65 V: C2.2, R5.1, R17.1, U2.13 (-), U2.14, U5.6 (REF), U8.3, U8.4
/3V7: C8.1, J1.1, U4.1 (IN), U4.3 (EN)
/CS: U1.2 (~CS), U7.1 (D0)
/CS1: U3.1, U7.3 (D2)
/DIN: U1.16 (DIN), U3.3, U7.11 (D10)
/DOUT: U1.15 (DOUT/~DRDY), U7.10 (D9)
/DRDY: U1.14 (~DRDY), U7.2 (D1)
/IAout: C3.1, U5.7 (VOUT)
/In+: C7.2, U5.4 (IN+), U6.3, U8.2
/In-: C7.1, U5.1 (IN-), U6.4, U8.1
/Negative_Electrode: TP1.1, U6.1
/Positive_Electrode: TP2.1, U6.2
/Reference_Electrode: R17.2, TP3.1
/SCLK: U1.1 (SCLK), U3.2, U7.9 (D8)
/Vout: U1.11 (AIN0/REFP1), U2.8, U3.6
GND: C5.2, C6.2, C8.2, C9.2, C10.2, C11.2, C12.2, J1.2, R13.2, U1.4 (DGND), U1.5 (AVSS), U2.11 (V-), U4.2 (GND), U5.5 (VS-), U7.13 (GND)
unnamed: C1.1, R1.2, R6.3
unnamed: C3.2, C4.1, R3.1
unnamed: R2.1, U5.3 (RG)
unnamed: R2.2, U5.2 (RG)
unnamed: R4.2, U3.7
unnamed: C4.2, R5.2, U2.3 (+)
unnamed: R1.1, R3.2, U2.1, U2.2 (-)
unnamed: C2.1, R6.2, U2.5 (+)
unnamed: C1.2, U2.6 (-), U2.7, U2.10 (+)
unnamed: R4.1, U2.9 (-)
unnamed: R12.2, R13.1, U2.12 (+)

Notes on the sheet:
battery
Input Electrode
ADC Properties 1) Sampling Frequency: 2 kHz 2) Number of Bits: 12 Bits
INA
LDO
Ref Electrode
change RG

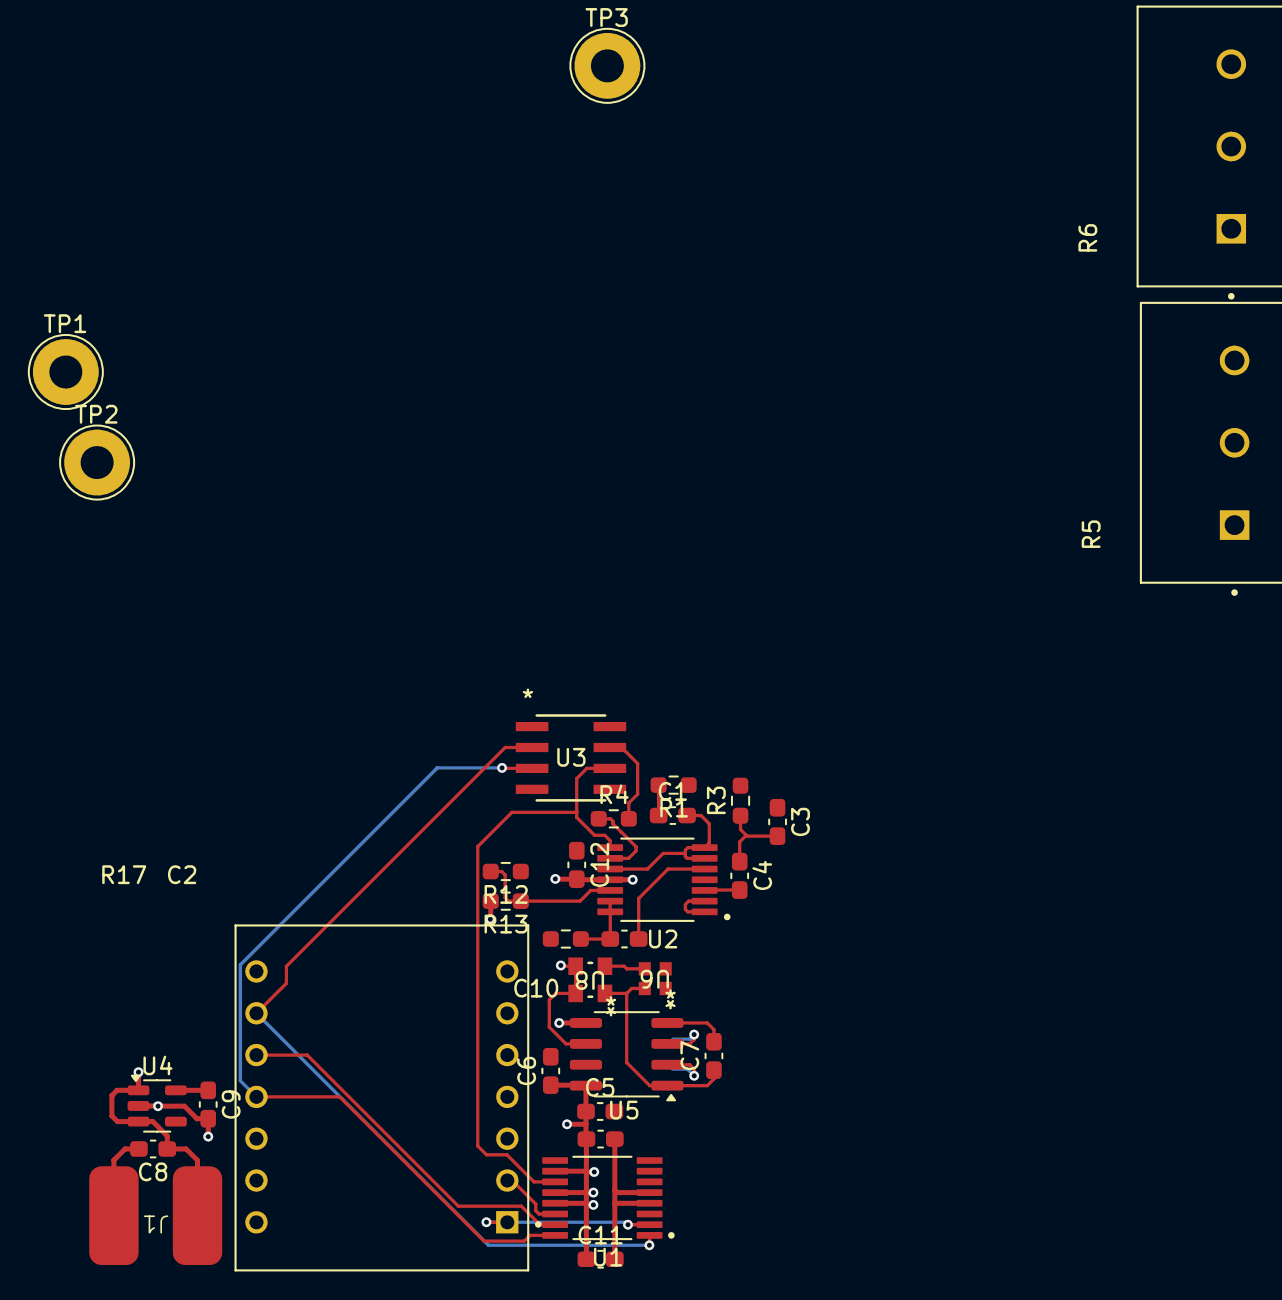
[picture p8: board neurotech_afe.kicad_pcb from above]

Board: 4 copper layers, 33 parts (1 on the bottom side), 28 nets.

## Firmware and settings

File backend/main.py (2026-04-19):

"""
FlexEMG backend – entry point.

Normal operation (real ESP32):
    python main.py

With live gesture classification (requires a saved model.pkl):
    python main.py --classify

Interactive training session (collect labelled data from the real ESP32
and train the classifier; model is saved to model.pkl when done):
    python main.py --train

Press Ctrl-C to stop.
"""

import argparse
import asyncio
import logging
import signal
import sys
from collections import deque
from pathlib import Path

import numpy as np

import config
from classifier import CLASSES, WINDOW_SAMPLES, STEP_SAMPLES, EMGClassifier
from esp32_client import create_esp32_reader
from signal_processor import SignalProcessor
from server import BroadcastServer

logging.basicConfig(
    level=logging.INFO,
    format="%(asctime)s  %(levelname)-8s  %(name)s  %(message)s",
    datefmt="%H:%M:%S",
)
logger = logging.getLogger("main")


# ── Pipeline task ─────────────────────────────────────────────────────────────

async def pipeline(
    queue: asyncio.Queue,
    processor: SignalProcessor,
    server: BroadcastServer,
    classifier: EMGClassifier | None = None,
) -> None:
    """
    Drain the sample queue, filter each sample, and broadcast.

    When *classifier* is provided (--classify mode), a sliding window of
    filtered samples is maintained and a gesture prediction is attached to
    every STEP_SAMPLES-th broadcast frame.
    """
    sample_count  = 0
    log_interval  = config.SAMPLE_RATE      # log once per second

    # Sliding window for the classifier (only used when classifier is not None)
    clf_window: deque[float] = deque(maxlen=WINDOW_SAMPLES)
    clf_step:   int          = 0
    last_gesture: str | None        = None
    last_confidence: float | None   = None

    while True:
        item = await queue.get()
        result = processor.process_sample(item["adc"])

        gesture    = None
        confidence = None

        if classifier is not None:
            clf_window.append(result["filtered"])
            clf_step += 1
            if len(clf_window) == WINDOW_SAMPLES and clf_step % STEP_SAMPLES == 0:
                label, conf   = classifier.predict(np.array(clf_window))
                last_gesture    = CLASSES[label]
                last_confidence = conf
            gesture    = last_gesture
            confidence = last_confidence

        await server.broadcast(
            ts=item["ts"],
            raw_voltage=result["raw_voltage"],
            filtered=result["filtered"],
            gesture=gesture,
            confidence=confidence,
        )

        sample_count += 1
        if sample_count % log_interval == 0:
            pred_str = f"  gesture={last_gesture} ({last_confidence:.0%})" if last_gesture else ""
            logger.info(
                "Processed %d samples  |  raw=%.4f V  filtered=%.4f V%s",
                sample_count,
                result["raw_voltage"],
                result["filtered"],
                pred_str,
            )


# ── Interactive training session (real hardware) ──────────────────────────────

async def training_session(
    queue: asyncio.Queue,
    processor: SignalProcessor,
    duration_secs: float = 10.0,
) -> EMGClassifier:
    """
    Collect labelled training data from the real ESP32 and train the model.

    The user is prompted to perform each movement for *duration_secs* seconds.
    A brief rest period is recorded between movements so the classifier can
    distinguish activation from baseline.
    """
    from classifier import MIN_SAMPLES_PER_CLASS

    clf        = EMGClassifier()
    clf_window: deque[float] = deque(maxlen=WINDOW_SAMPLES)
    clf_step   = 0

    async def _collect_class(label: int, name: str) -> int:
        nonlocal clf_step
        n_windows  = 0
        n_samples  = 0
        deadline   = asyncio.get_event_loop().time() + duration_secs
        logger.info("Recording '%s' for %.0f s …", name, duration_secs)

        while asyncio.get_event_loop().time() < deadline:
            item = await queue.get()
            result = processor.process_sample(item["adc"])
            clf_window.append(result["filtered"])
            clf_step  += 1
            n_samples += 1

            if len(clf_window) == WINDOW_SAMPLES and clf_step % STEP_SAMPLES == 0:
                clf.add_training_sample(np.array(clf_window), label)
                n_windows += 1

        logger.info("  Collected %d windows for '%s'.", n_windows, name)
        return n_windows

    for label, name in CLASSES.items():
        input(f"\n  >> Ready to record '{name}'.  Perform the movement and press Enter …")
        await _collect_class(label, name)
        input("  >> Rest.  Press Enter when ready for the next movement …")

    logger.info("Training classifier …")
    result = clf.train()
    logger.info(
        "Training complete  |  accuracy=%.1f%%  samples=%d  counts=%s",
        result["accuracy"] * 100,
        result["n_samples"],
        {CLASSES[k]: v for k, v in result["counts"].items()},
    )
    return clf


# ── Main ──────────────────────────────────────────────────────────────────────

async def main(args: argparse.Namespace) -> None:
    logger.info("=" * 60)
    logger.info("FlexEMG Backend")
    logger.info("  Sample rate  : %d Hz", config.SAMPLE_RATE)
    logger.info("  Bandpass     : %.0f – %.0f Hz", config.BANDPASS_LOW_HZ, config.BANDPASS_HIGH_HZ)
    logger.info("  Notch        : %.0f Hz  (Q=%.1f)", config.NOTCH_FREQ_HZ, config.NOTCH_Q)
    logger.info("  ESP32 mode   : %s", config.ESP32_MODE)
    logger.info("  Server       : ws://%s:%d", config.SERVER_HOST, config.SERVER_PORT)
    logger.info("=" * 60)

    raw_queue: asyncio.Queue = asyncio.Queue(maxsize=4096)
    processor        = SignalProcessor()
    broadcast_server = BroadcastServer()

    def on_esp32_connect():
        processor.reset()
        logger.info("ESP32 connected – filter state reset.")

    def on_esp32_disconnect():
        logger.warning("ESP32 disconnected.")

    # ── Training mode ─────────────────────────────────────────────────────────
    if args.train:
        logger.info("TRAINING MODE – connect to ESP32 and follow the prompts.")
        esp32_task = asyncio.create_task(
            create_esp32_reader(raw_queue, on_esp32_connect, on_esp32_disconnect),
            name="esp32-reader",
        )
        # Wait until the ESP32 has connected and we have some data
        await asyncio.sleep(2.0)
        clf = await training_session(raw_queue, processor)
        clf.save()
        logger.info("Model saved to %s", EMGClassifier.DEFAULT_MODEL_PATH
                    if hasattr(EMGClassifier, "DEFAULT_MODEL_PATH") else "model.pkl")
        esp32_task.cancel()
        return

    # ── Classification mode ───────────────────────────────────────────────────
    clf: EMGClassifier | None = None
    if args.classify:
        try:
            clf = EMGClassifier.load()
            logger.info(
                "Loaded classifier  (training accuracy=%.1f%%)",
                (clf.train_accuracy or 0) * 100,
            )
            logger.info("Gestures: %s", list(CLASSES.values()))
        except FileNotFoundError as exc:
            logger.error("%s", exc)
            sys.exit(1)

    # ── Normal (or classify) operation ────────────────────────────────────────
    esp32_task = asyncio.create_task(
        create_esp32_reader(raw_queue, on_esp32_connect, on_esp32_disconnect),
        name="esp32-reader",
    )
    pipeline_task = asyncio.create_task(
        pipeline(raw_queue, processor, broadcast_server, classifier=clf),
        name="pipeline",
    )
    server_task = asyncio.create_task(
        broadcast_server.serve(),
        name="broadcast-server",
    )

    loop = asyncio.get_running_loop()
    for sig in (signal.SIGINT, signal.SIGTERM):
        loop.add_signal_handler(sig, _shutdown, esp32_task, pipeline_task, server_task)

    await asyncio.gather(esp32_task, pipeline_task, server_task)


def _shutdown(*tasks: asyncio.Task) -> None:
    logger.info("Shutting down …")
    for t in tasks:
        t.cancel()


if __name__ == "__main__":
    parser = argparse.ArgumentParser(description="FlexEMG backend")
    group = parser.add_mutually_exclusive_group()
    group.add_argument(
        "--train", action="store_true",
        help="Interactive training session: collect labelled EMG from the ESP32 "
             "and save a gesture classifier to model.pkl",
    )
    group.add_argument(
        "--classify", action="store_true",
        help="Load model.pkl and broadcast real-time gesture predictions "
             "alongside the filtered signal",
    )
    args = parser.parse_args()

    try:
        asyncio.run(main(args))
    except asyncio.CancelledError:
        pass
    logger.info("Stopped.")

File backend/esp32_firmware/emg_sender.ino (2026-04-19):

/*
 * FlexEMG – ESP32 firmware (reference)
 *
 * Reads the EMG signal from GPIO 34 (ADC1_CH6) at 1000 Hz and streams
 * raw 12-bit ADC values to the Python backend via WebSocket.
 *
 * Data format sent:  {"v": 2048}\n
 *
 * Libraries required (install via Arduino Library Manager):
 *   • ArduinoWebsockets  by Gil Maimon  (v0.5.x)
 *   • ArduinoJson        by Benoit Blanchon  (v6.x)
 *
 * Board: "ESP32 Dev Module" (or your specific variant)
 *
 * IMPORTANT: GPIO 34 is input-only (no internal pull-up).
 *            Keep the EMG signal within 0–3.3 V at all times.
 */

#include <WiFi.h>
#include <ArduinoWebsockets.h>
#include <ArduinoJson.h>

using namespace websockets;

// ── Configuration ────────────────────────────────────────────────────────────
const char* WIFI_SSID     = "YOUR_SSID";
const char* WIFI_PASSWORD = "YOUR_PASSWORD";

// Backend Python host and port (SERVER_PORT in config.py)
// The ESP32 connects TO the backend, which acts as the WS server.
// If you want the ESP32 to be the WS server instead, swap the roles and
// update ESP32_MODE = "websocket" + ESP32_WS_URI in config.py accordingly.
const char* BACKEND_HOST  = "192.168.1.50";   // ← IP of the machine running main.py
const uint16_t BACKEND_PORT = 8765;

const int   EMG_PIN        = 34;   // ADC1_CH6 – input-only pin
const int   SAMPLE_RATE_HZ = 2000; // must match config.SAMPLE_RATE
const int   SAMPLE_INTERVAL_US = 1000000 / SAMPLE_RATE_HZ;  // 1000 µs

// ── Globals ───────────────────────────────────────────────────────────────────
WebsocketsClient wsClient;
bool wsConnected = false;

unsigned long lastSampleUs = 0;

// ── WiFi helpers ──────────────────────────────────────────────────────────────
void connectWiFi() {
    Serial.print("Connecting to WiFi");
    WiFi.begin(WIFI_SSID, WIFI_PASSWORD);
    while (WiFi.status() != WL_CONNECTED) {
        delay(500);
        Serial.print(".");
    }
    Serial.println();
    Serial.print("Connected. IP: ");
    Serial.println(WiFi.localIP());
}

// ── WebSocket helpers ─────────────────────────────────────────────────────────
void connectWebSocket() {
    Serial.println("Connecting to backend WebSocket…");
    wsConnected = wsClient.connect(BACKEND_HOST, BACKEND_PORT, "/");
    if (wsConnected) {
        Serial.println("WebSocket connected.");
    } else {
        Serial.println("WebSocket connection failed – will retry.");
    }
}

// ── Arduino setup / loop ──────────────────────────────────────────────────────
void setup() {
    Serial.begin(115200);

    // Configure ADC: 12-bit, 0–3.3 V (attenuation 11 dB covers full range)
    analogReadResolution(12);
    analogSetAttenuation(ADC_11db);
    pinMode(EMG_PIN, INPUT);

    connectWiFi();

    wsClient.onEvent([](WebsocketsEvent event, String data) {
        if (event == WebsocketsEvent::ConnectionOpened) {
            wsConnected = true;
        } else if (event == WebsocketsEvent::ConnectionClosed) {
            wsConnected = false;
            Serial.println("WebSocket closed.");
        }
    });

    connectWebSocket();
}

void loop() {
    // Maintain WebSocket connection
    if (!wsConnected) {
        delay(3000);
        connectWebSocket();
        return;
    }
    wsClient.poll();

    // Sample at exactly SAMPLE_RATE_HZ using micros() timer
    unsigned long now = micros();
    if (now - lastSampleUs < SAMPLE_INTERVAL_US) {
        return;  // not time yet
    }
    lastSampleUs = now;

    int adcValue = analogRead(EMG_PIN);   // 0–4095

    // Build JSON payload
    StaticJsonDocument<32> doc;
    doc["v"] = adcValue;
    char buf[32];
    serializeJson(doc, buf);

    wsClient.send(buf);
}

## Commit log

2026-03-08 created asc file with the circuit's full gain. Does not include any frequency filters
2026-03-08 added sallen key topology to circuit 20-500 HZ
2026-04-05 kabeer's schematic added
    [ESP32C3.step, neurotech_afe.kicad_pcb, neurotech_afe.kicad_sch]
2026-04-05 final kiCad pushed to main
    [ESP32C3.step, finalKiCad.kicad_sch, neurotech_afe.kicad_pcb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]
2026-04-05 Track only KiCad sources; remove LTSpice prototype files
2026-04-05 added final schematic
    [neurotech_afe.kicad_sch]
2026-04-08 fixed ERC errors
    [neurotech_afe.kicad_sch]
2026-04-08 assigned passive footprints
    [neurotech_afe.kicad_sch]
2026-04-08 cleaned up schm
    [neurotech_afe.kicad_sch]
2026-04-09 Created pcb layout and started wiring
    [neurotech_afe.kicad_pcb, neurotech_afe.kicad_sch]
2026-04-09 chore: untrack generated KiCad files
2026-04-09 chore: gitignore KiCad generated files
2026-04-10 added csv for bom
    [neurotech_afe.csv]
2026-04-10 reassigned footprints and values
    [neurotech_afe.kicad_sch]
2026-04-12 Update schematic, symbols, and footprints
    [neurotech_afe.kicad_sch]
2026-04-17 footprints and started layout
    [ADS1220IPW.step, ESP32C3.step, OPA4322AIPWR.step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]
2026-04-19 Add Python backend: signal filtering, gesture classifier, and simulator
2026-06-18 Add project README with photos and clean up tracked build artifacts
    - Replace the placeholder README with a project overview, architecture
    diagram, hardware notes, photo gallery, and getting-started guide
    - Add project photos with descriptive filenames
    - Stop tracking __pycache__, KiCad lock/backup files, and a stray
    submodule reference; broaden .gitignore to cover them
